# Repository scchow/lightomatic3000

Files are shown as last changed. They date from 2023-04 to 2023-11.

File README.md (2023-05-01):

# Lightomatic-3000

The Lightomatic-3000 is a state-of-the-art "robot" (in the loosest sense of the word) that keeps lights from dimming/turning off due to poorly calibrated presence/ambient lighting systems.

<p align="center">
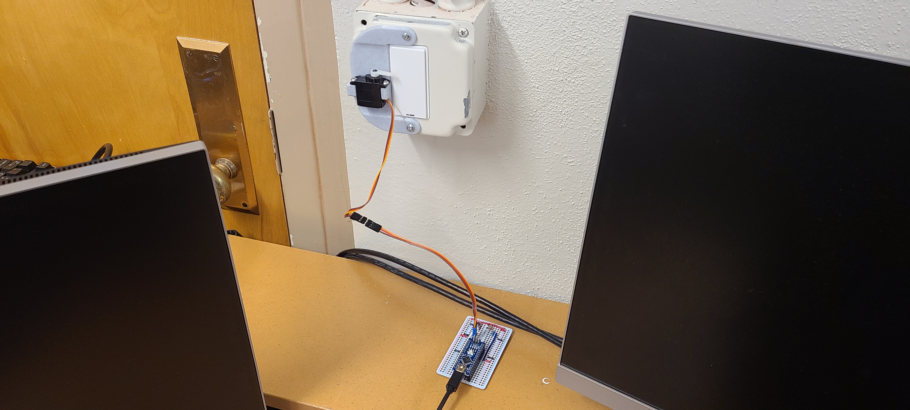
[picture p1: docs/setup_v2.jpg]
Final Setup.
  
</p>

## The Problem: Got a light?

The lighting system in a certain building has an energy saving feature that dims and turns off the light if:
- the ambient light is above a certain threshold
- no motion has been detected for a certain amount of time

Unfortunately, the ambient light sensor seems to be miscalibrated or mounted in a location not representative of the actual ambient light in the room it controls, causing the lights to dim/turn off in the middle of the workday. Dim lighting conditions in offices can lead to significant eyestrain and decreased productivity.

Additionally, the motion detector will also fail to detect the presence of people working on their computer at night, causing the lights to go out and requiring someone to grope in the dark to find the light switch, which is not ideal.

## Enter the Lightomatic-3000

The Lightomatic-3000 is a simple, lightweight, and cost-effective way to keep the lights on. 

### Photoresistor

It uses a photo-resistor to sense the ambient light in the room. By setting thresholds for lights dimming and off, it can differentiate whether the lights are just beginning to dim, or if they are fully off. Note that the thresholds will vary depending on resistor value and photoresistor, so additional retuning may be necessary if those parts are replaced.

### Servo for Button Pressing
Once it detects the lights are beginning to dim or have turned off, it actuates a servo to press the light switch. 

- If the lights are dimming but not off, it will double press the light switch to turn the lights off and on again at full brightness. 
- If the lights are fully off, it will single press the light switch to turn the lights back on. 

### Enable/Disable Switch (Optional)
It also features an optional switch that can be used to enable/disable the system when you do want to keep the lights off.

## Parts Needed
- Arduino + USB power
- 5V servo (3.3V would work)
- Photoresistor
- Resistor (10k ohm)
- SPDT switch (optional)
- Mounting method (Tape or 3d printed mount)

## Assembling

1. Wire up the circuit below either using a breadboard or a protoboard.
2. Check:
- Photoresistor values are being read correctly. (Also a good time to check threshold values.)
- Servo actuation when it is dark enough. (Also good time to check servo angle is enough to press the switch without breaking anything.)
3. Flash the code in the `lightomatic3000` folder onto the Arduino and unplug.
4. Mount servo to light switch.
5. Plug arduino in
6. Let there be light!

## Circuit Schematic

<p align="center">
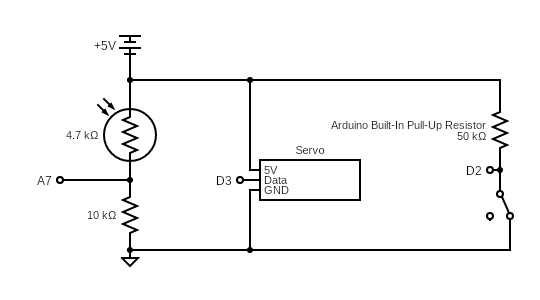
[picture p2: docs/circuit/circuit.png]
Circuit Schematic
  
</p>

## Assembled Protoboard
<p align="center">
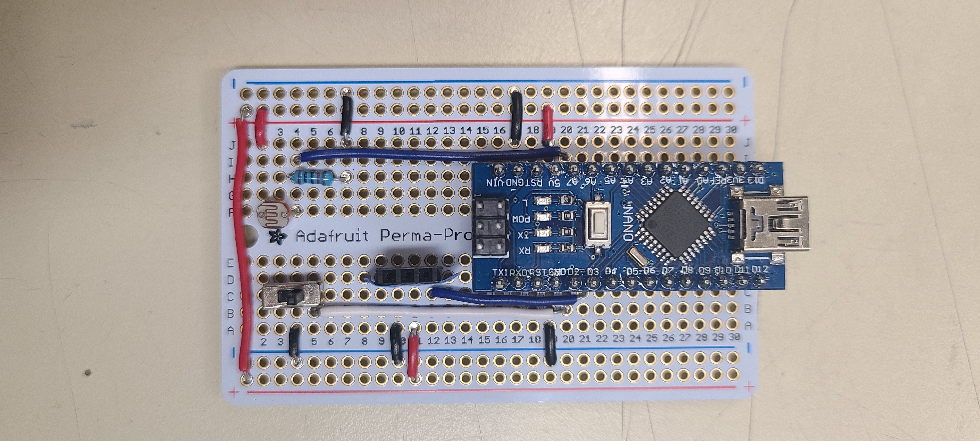
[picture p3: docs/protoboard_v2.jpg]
Image of assembled protoboard.
  
</p>

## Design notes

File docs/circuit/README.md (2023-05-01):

The circuit diagram was created with https://www.circuit-diagram.org.

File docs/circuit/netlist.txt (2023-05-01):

* Netlist created with www.circuit-diagram.org
* circuit
'microcontroller #4:0 #0:1 #2:2 header=Servo sz=6 p0=5V p1= p2=Data p3= p4=GND p5= p6= p7= p8= p9= p10= p11= p12= p13= p14= p15= p16= p17= p18= p19= p20= p21= p22= p23= p24= p25= p26= p27= p28= p29= p30= p31= p32= p33= p34= p35= p36= p37= p38= p39=
R1 1 3 50000
'changeoverswitch a:3 c:0 t=Changeover closed=False
V2 ? 1 5
V3 0 0
R4 1 4 4700
R5 4 0 10000

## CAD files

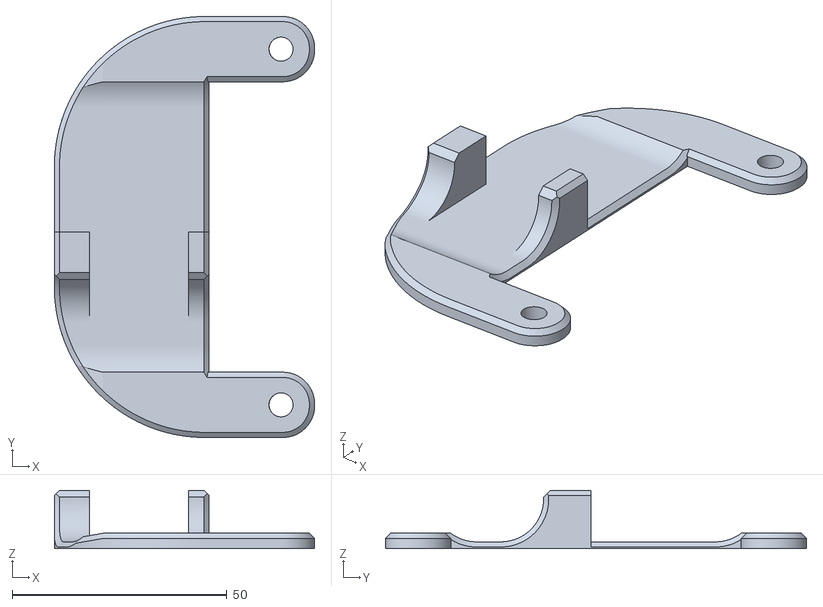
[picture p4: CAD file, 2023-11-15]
models/light_switch_flipper_mount.stl
60.6 x 98.0 x 13.6

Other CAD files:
models/light_switch_flipper_mount.f3d

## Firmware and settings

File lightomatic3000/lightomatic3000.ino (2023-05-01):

/**
 * @file lightomatic3000.ino
 * @author Scott Chow
 * @brief Runs the lightomatic3000 program to keep the lights on
 */

#include <Servo.h>

// Serial Comms variables
bool debug = true;
bool plot = true;
int baud_rate = 9600;

// Servo variables
Servo servo;          // create servo object to control a servo
int pos = 0;          // variable to store the servo position
int press_angle = 40; // how much the servo should turn to press the button

// Room state variables
static bool switch_on = false;
static bool lights_dimming = false;
static bool lights_off = false;

// Photoresistor light detection variables
// light levels calibrated based on 10k resistor running off of 5V
// Estimated based on 3.3V values (should be about 1.5x the 3.3V values)
int lightLevel = 0;
int threshold_dimming = 825; // threshold for the room lights to be considered dimming (525*1.515)
int threshold_off = 600;     // threshold for the room lights to be considered off (400*1.515)

// Pin Inputs
const int switch_pin = 2;
const int photoresistor_pin = A7;
// Pin Outputs
const int servo_pin = 3;
const int status_led = LED_BUILTIN; // 13 is built in LED

/**
 * @brief Updates the light status based on the photoresistor reading
 *        and prints out the status to a serial plotter if flag is set
 */
void update_light_status()
{
  photoresistor_loop(photoresistor_pin); // check room status
  if (debug || plot)
  {
    Serial.print("light_level:");
    Serial.print(lightLevel);
    Serial.print(",");
  }
  lights_off = lightLevel <= threshold_off;
  lights_dimming = !lights_off & (lightLevel <= threshold_dimming);
  if (plot)
  {
    Serial.print("lights_off:");
    Serial.print(1000 * (int)lights_off);
    Serial.print(",");
    Serial.print("lights_dimming:");
    Serial.print(1000 * (int)lights_dimming);
    Serial.print(",");
  }
}

/**
 * @brief Updates the switch status based on the switch reading
 *       and prints out the status to a serial plotter if flag is set
 */
void update_switch_status()
{
  switch_loop(switch_pin, status_led); // check if switch is on
  // If we are plotting, print switch status in
  // plottable format
  if (plot)
  {
    // Multiply by 1000 to make switch show up on plot with light level
    Serial.print("switch:");
    Serial.print(1000 * (int)switch_on);
    Serial.print(",");
  }
  // Otherwise just print status message as normal
  else if (debug)
  {
    Serial.print("Status: switch=");
    Serial.println(switch_on ? "on" : "off");
  }
}

/**
 * @brief Sets up the servo, photoresistor, and switch.
 *        Sets up serial comms if debug or plot flags are set
 */
void setup()
{
  servo_setup(servo_pin);
  photoresistor_setup(photoresistor_pin);
  switch_setup(switch_pin, status_led);

  if (debug | plot)
  {
    Serial.begin(baud_rate);
  }
  delay(1000 * 3); // wait 3 seconds before starting
}

/**
 * @brief Main execution loop
 *
 */
void loop()
{
  update_switch_status();
  update_light_status();

  // if the switch is on, and the room is dark, press the button
  if (switch_on)
  {
    // if lights are dimming give it 2 seconds to see if it is actually off
    // because someone pressed the light switch
    if (lights_dimming)
    {
      delay(2000);
      update_light_status();
    }
    // if the light are still dimming, do a double press
    if (lights_dimming)
    {
      press_button(press_angle);
      delay(1000);
      press_button(press_angle);
      if (debug & !plot)
      {
        Serial.println("Status: Lights/Dimming: Double Press");
      }
    }
    // if the lights are fully off, do a single press
    if (lights_off)
    {
      press_button(press_angle);
      if (debug & !plot)
      {
        Serial.println("Status: Lights/Off: Single Press");
      }
    }
  }
  if (debug | plot)
  {
    Serial.println();
  }
  delay(1000); // Run at 1Hz
}

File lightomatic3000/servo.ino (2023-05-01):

/**
 * @brief Code for interfacing with the servo
 *
 * Based on the Arduino Servo library example:
 * https://docs.arduino.cc/learn/electronics/servo-motors
 *
 */

/**
 * @brief Sets the pin provided as a servo pin,
 *        sets the angle to zero, and waits 0.25 seconds
 *
 * @param servo_pin the Digital pin number for the servo
 */
void servo_setup(int servo_pin)
{
  // put your setup code here, to run once:
  servo.attach(servo_pin); // attaches the servo on pin 9 to the servo object
  servo.write(0);          // start at home position
  delay(250);
}

/**
 * @brief Presses the light switch by moving the servo to the specified angle
 *
 * @param angle the angle (in degrees) to move the servo
 */
void press_button(int angle)
{
  // Move servo to specified angle
  // run_servo(angle);
  servo.write(angle);
  delay(250); // wait 0.25 second
  // move servo back to start
  servo.write(0);
}

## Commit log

2023-03-24 Working MVP of light presser
    - Detects when room gets darker
    - Presses light switch when room is dark enough
    - Add on/off switch to disable functionality
2023-03-25 Code refactor, double tap switch
    - Refactored code to reduce the number of global variables
    - Implemented double tapping switch
    to turn lights off and on
    when light is only dimming and not fully off.
2023-03-25 Added debug, Fix indentation
    - Added debug flag for printing to serial
    - Fixed some indentation issues
    [lightomatic3000.ino]
2023-04-03 Added proper delays between button presses
2023-04-24 5V Photoresistor/Serial Plotting
    - Adding plot flag
    - When plot or debug is enabled, print out light measurement status
    message formatted so that serial plotter can plot the data
    - Adjusted light levels with best guess for photoresistor running off of
    5 volts
2023-04-24 Updating Thresholds/Plot logic/Servo
    - Updated thresholds based on light sensor measurements
    - Update servo turn angle
    - Better logging to serial depending on if plot is enabled
    - Use simpler code for actuating servo
2023-04-24 Serial Print Streamline, Refactor light logic
    - Moved all serial prints to the main file
    - Only print new line (thus update serial plot) once per loop
    - Refactored light dimming/off logic to be more straightforward
    - Removed unused servo turning code.
2023-04-28 Updated Readme / Added Circuit Diagrams
    - Updated Readme with instructions
    - Circuit Diagrams made in: https://www.circuit-diagram.org/editor/
2023-05-01 Updated circuit diagram
2023-05-01 Fixing image size on mobile
    - Since our setup image is now wide enough, don't need to specify
    height/width, which breaks compatibility with mobile
    - Added center alignment for circuit diagram and protoboard.
2023-05-01 Updated Circuit Diagram
    - Fixed switch pullup resistor diagram
2023-11-15 The 3d model files used for mounting the servo to the lightswitch
    [light_switch_flipper_mount.f3d, light_switch_flipper_mount.stl]
